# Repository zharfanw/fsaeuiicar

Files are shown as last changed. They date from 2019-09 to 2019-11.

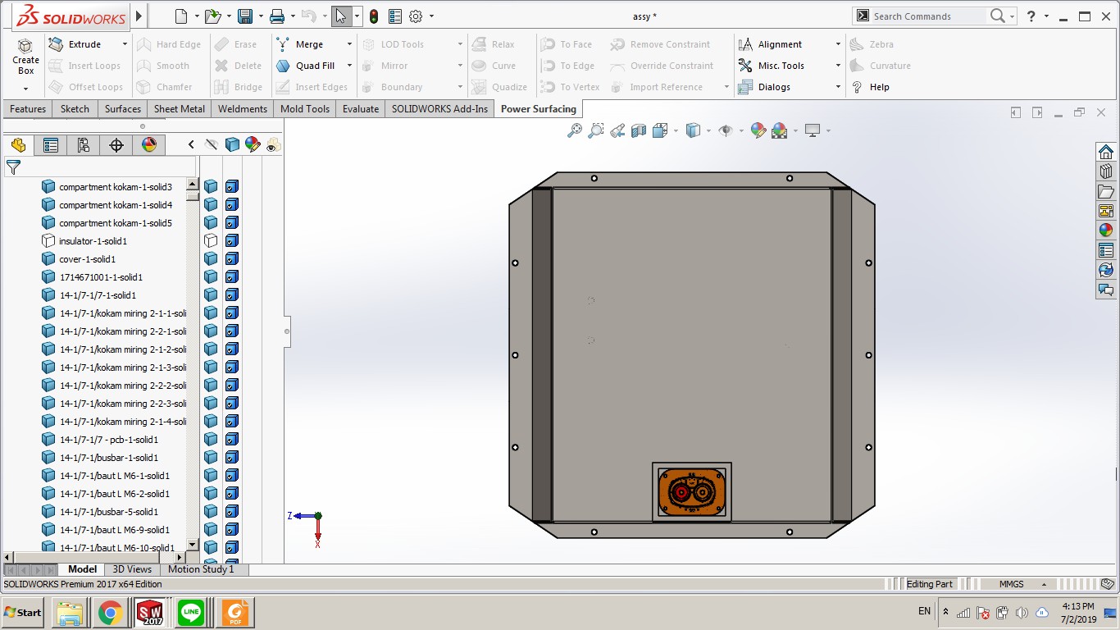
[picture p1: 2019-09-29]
Gambar/messageImage_1562058789128.jpg

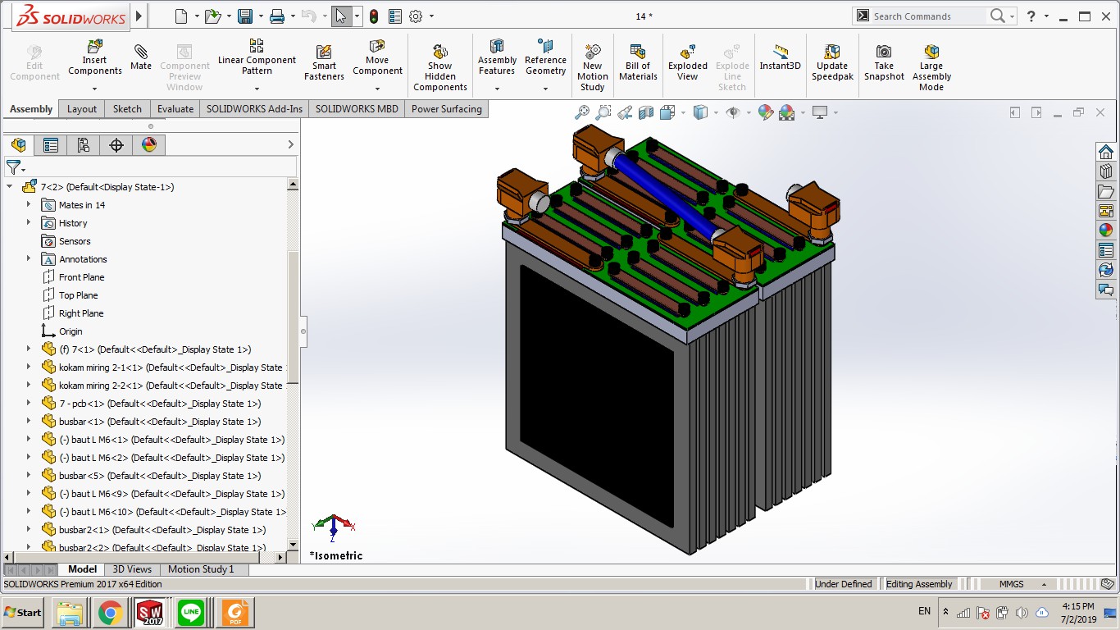
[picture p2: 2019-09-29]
Gambar/messageImage_1562058909561.jpg

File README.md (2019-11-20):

# UIIs Formula Students Car 2018
Repo ini merupakan dokumentasi dari mobil listrik UII 2018.
## Dokumentasi Link
Full PDF Dokumentasi [klik dsini](https://github.com/zharfanw/fsaeuiicar/blob/master/Dokumentasi/Dokumentasi%20Elektrik%20Mobil%20SFJ2018%20UII_v2.pdf "Dokumentasi Elektrik Mobil SFJ2018 UII_v2.pdf")
## Kontributor Dokumentasi

 - Muhammad Zharfan Wiranata
 - Muh Fanriado
 - Kristamayu
 - Rudi Arta
 - Akhid Sulthoni
 - Fauzi HPM
 - Muh Dzulfiqar
 - Refhan Naparin
 - Hilal Pambudi
 - Faiz Isbat
 - Muh Iqbal
 - Jabar Lazuarde

<!--stackedit_data:
eyJoaXN0b3J5IjpbLTQxOTc5MTk5MiwxOTc0MTc4MTIxLDU1Nz
E1NDAyNl19
-->

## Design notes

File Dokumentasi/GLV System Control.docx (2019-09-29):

 1. Shutdown system

Rule yang terkait dengan Shutdown Circuit

EV 5.7.3:

EV 5.1.2:

EV 5.1.10:

EV 5.1.11:

EV 4.2.4:

EV 4.10.1:

   1.1. Skematik Shutdown System

Skematik diatas merupakan rangkaian shutdown system untuk mengendalikan kontaktor tractive system. Rangkaian menggunakan relay SPDT untuk interlock IMD, AMS dan BSPD. Relay diatas di drive dengan transistor pnp yang dipicu dari IMD, AMD, dan BSPD. Selanjutnya rangkaian tersebut dilengkapi dengan indikator setiap interlock, karena hanya menggunakan sebuah tombol reset. Selain interlock tersebut terdapat 7 switch yang digunakan(HVD, Shutdown right, Shutdown left, Shutdown dashboard, inertia switch, BOTS, dan TSMS) dan setiap switch terhubung Normally Close(NC). Skematik rangkaian diatas digunakan pada mobil FSAE UII gen 1 untuk SFJ 2018 dan telah diuji serta layak digunakan.

Gambar 1: Rangkaian Shutdown System v1.0

Pada rangkaian shutdown system v1.0 semua relay interlock menggunakan Normally Close(NC) sehingga jika ada kerusakan pada rangkaian drive pada relay(contoh: transistor terbakar, saluran IMD/AMS/BSPD putus atau lainnya), rangkaian masih bisa menyalakan tractive system walaupun terjadi kesalahan pada mobil. Tentu hal kejadian tersebut menjadi resiko besar, sehingga dibuat alternatif yang lain untuk shutdown system mobil selanjutnya. Selain itu untuk rangkaian BSPD juga masih perlu diperbaiki yang akan dibahas subbab (1.1.a). Oleh karena itu, rangkaian shutdown system dibuat seperti gambar xx.

Rangkaian shutdown system v2.0 masih dalam bentuk simulasi, namun secara simulasi lebih baik dari pada shutdown system v1.0, karena untuk switch interlock menggunakan kaki Normally Open (NO). Dan juga pada rangkaian menggunakan IC logic CMOS 12 volt, sehingga aliran tidak perlu regulator. Shutdown system v2.0 tidak akan mengaktifkan tractive system jika saluran IMD, AMS, dan BSPD putus atau bahkan rangkaian untuk drive relay(transistor mosfet, IC 40xx series, dll) rusak atau bermasalah. Sama seperti shutdown system v1.0, rangkaian hanya menggunakan sebuah reset dan setiap interlock memiliki indikator.

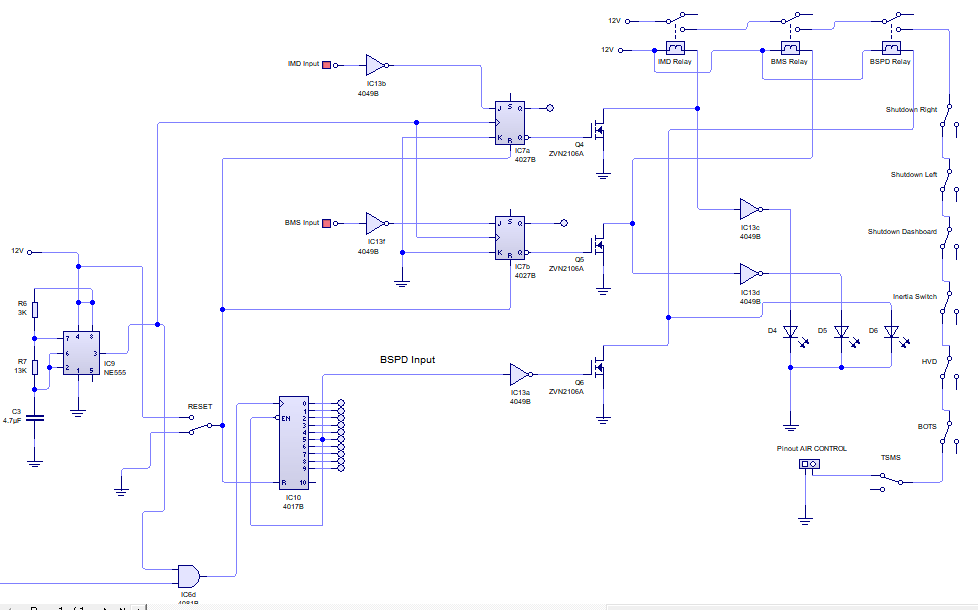
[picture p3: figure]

Gambar 2: Rangakian Shutdown system v2.0

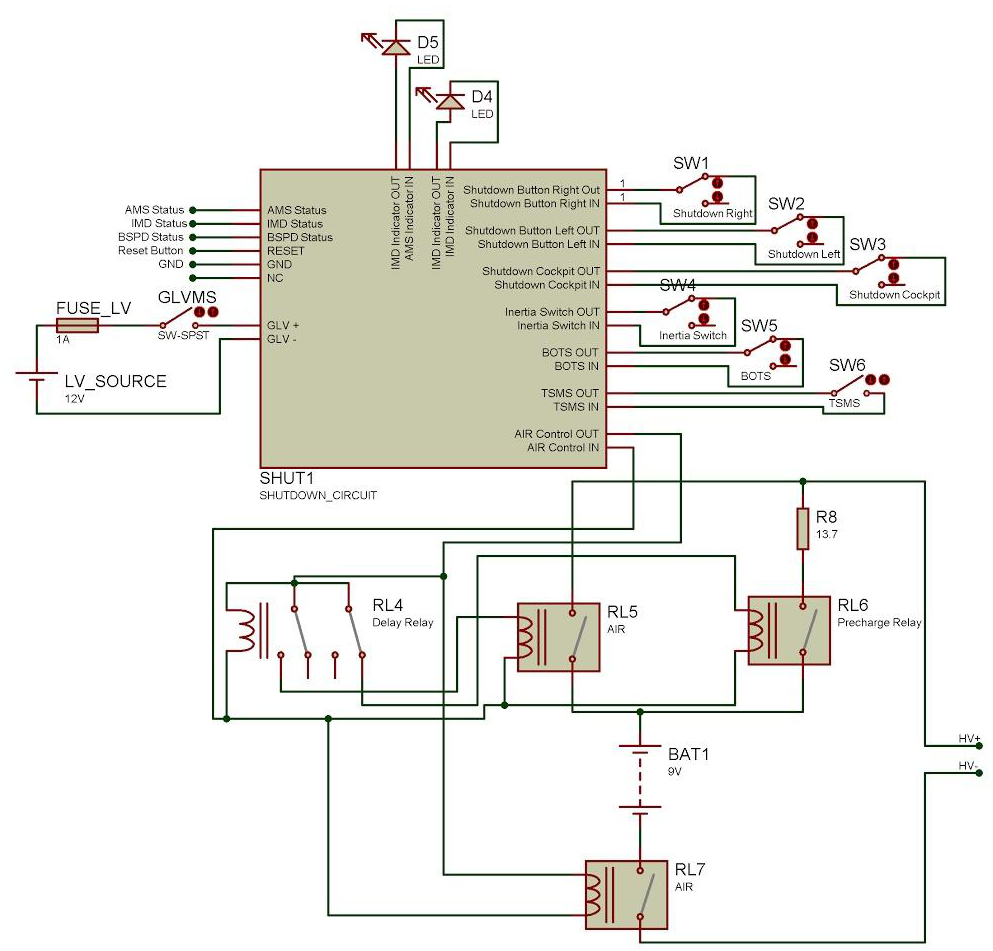
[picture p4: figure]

Gambar 3: AIR Control untuk untuk shutdown circuit

Setelah rangkaian shutdown system , outputnya akan masuk ke rangkaian AIR Control dinama pada rangkaian tang mengendalikan Precharge dan Discharge pada tractive system yang akan dijelaskan pada subbab xx.

     a) Interlock IMD

IMD merupakan perangkat untuk memonitoring resistansi antara chassis/ground dan pole negatif dari tractive system. IMD memiliki 2-3 Output, namun untuk rangkaian shutdown system, hanya menggunakan sebuah output yakni OKHS pada pin 7, karena IMD yang digunakan pada EV FSAE UII sesuai dengan datasheet yang telah diberikan. Untuk lebih jelas tentang spesifikasi IMD yang digunakan, terdapat pada tabel dibawah ini

Make / Model | Bender IR155
Supply voltage | 12 VDC
Environmental temperature range: | -40 … +105°C
Self-test interval: | after power on and every 5 minute
High voltage range: | DC 0..800V
Set response value: | 200kΩ (500Ω/Volt)
Max. operation current: | 150mA
Approximate time to shut down at 50% of the response value: | 5s
Datasheet | Datasheet

Berdasarkan datasheet IMD memiliki rangkaian internal pada pinout IMD seperti illustrasi dibawah ini, (OKHS mengikuti rangkaian M-)

Oleh karena itu keluarannya di pulldown dengan resistor 2.2K ohm. Kemudian jika resistansi antara chassis/ground dan pole negative tractive system dibawah standard resistansi IMD, maka output tersebut akan berlogika 0, begitu pula sebaliknya. Sehingga untuk pada interlock IMD untuk shutdown system v1.0 menggunakan rangkaian seperti dibawah ini,

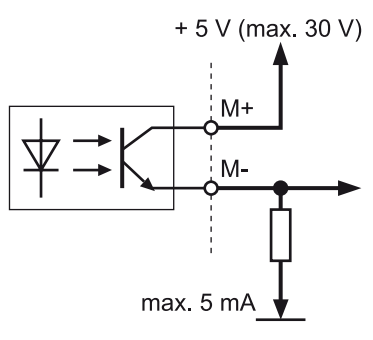
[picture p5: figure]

Gambar 4: Rangkaian Internal output OKHS

Gambar 5: Interlock IMD pada shutdown system v1.0

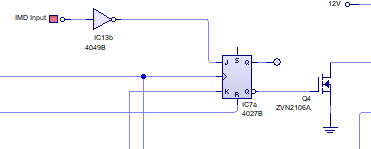
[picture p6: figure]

Gambar 6: Interlock IMD pada shutdown system v2.0

Tentang batasan standar resitansi antara chassis/ground dan HV untuk mobil EV FSAE UII adalah 80k Ohm, resistansi ini berdasarkan rule EV5.5 dimana untuk mobil tersebut memliki 320 Volt, sehingga mobil harus IMD dengan nilai responsenya adalah 500ohm/volt yang artinya untuk mobil bernilai 160k ohm, selanjutnya untuk pengujian IMD pada mobil menggunakan setengah dari nilai response tersebut. Untuk pengujian IMD tersebut, langkah kerja IMD adalah sebagai berikut:

1. sistem LV menyala terlebih dahulu, kemudian IMD menyala dan terhubung dengan HV serta tidak tedeteksi kesalahan pada IMD.
2. Kemudian pada Technical Inspection, maka digunakan resistor 80k ohm untuk menghubungkan antara GLV dan -HV
3. Setelah terdeteksi kesalahan, output OKHS akan active low atau berlogika nol
4. Kemudian dengan rangkaian shutdown system diatas, maka akan terjadi interlock dan menahan kondisi sampai tombol reset ditekan.
     b) Interlock BMS

BMS yang digunakan untuk mobil merupakan ORION BMS, sehingga output BMS yang digunakan shutdown system adalah pin multi purpose output pada pin ke 23. Rangkaian output secara internal di ilustrasikan pada gambar xx

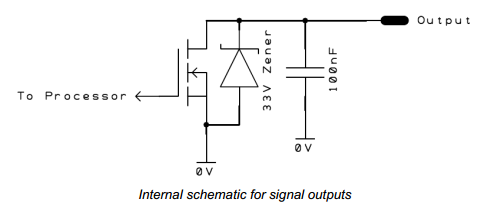
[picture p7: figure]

Gambar 7: Rangkaian internal output ORION BMS

Dengan rangkaian tersebut, maka untuk memanfaatkan output tersebut untuk memicu interlock pada shutdown system maka digunakan rangkaian seperti dibawah ini

Gambar 8: Rangkaian interlock pada BMS pada shutdown system v1.0

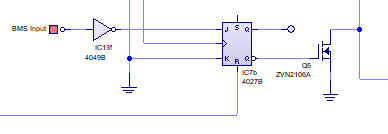
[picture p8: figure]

Gambar 9: Rangkaian Interlock BMS pada shutdown system v2.0

Sinyal multi purpose output pada ORION BMS sejatinya bisa diatur pada aplikasi desktop yang disediakan oleh ORION BMS, namun pada rangkaian interlock diatas telah diatur bahwa output keluaran ORION BMS tersebut ketika terjadi kesalahan adalah active low.

Output

     c) Interlock BSPD

Aturan BSPD

Cara membuat rekayasa interlock

   1.2. Switch untuk Shutdown Circuit
   1.3. Location Switch

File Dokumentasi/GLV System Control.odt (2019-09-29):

Sistem Kontrol pada Low Voltage system Mobil FSAE UII gen 1

Ditulis oleh:

Muhammad Zharfan Wiranata (14524109)

UASC Research Team

Fakultas Teknologi Industri

Universitas Islam Indonesia

2018

1. Sistem Low voltage Mobil FSAE UII gen 1

fasd

2. Shutdown system

Rule yang terkait dengan Shutdown Circuit

EV 5.7.3:

EV 5.1.2:

EV 5.1.10:

EV 5.1.11:

EV 4.2.4:

EV 4.10.1:

  1. Skematik Shutdown System

Skematik pada gambar 1 merupakan rangkaian shutdown system untuk mengendalikan kontaktor tractive system. Rangkaian menggunakan relay SPDT untuk interlock IMD, AMS dan BSPD. Relay diatas di drive dengan transistor pnp yang dipicu dari IMD, AMD, dan BSPD. Selanjutnya rangkaian tersebut dilengkapi dengan indikator setiap interlock, karena hanya menggunakan sebuah tombol reset. Selain interlock tersebut terdapat 7 switch yang digunakan(HVD, Shutdown right, Shutdown left, Shutdown dashboard, inertia switch, BOTS, dan TSMS) dan setiap switch terhubung Normally Close(NC). Skematik rangkaian diatas digunakan pada mobil FSAE UII gen 1 untuk SFJ 2018 dan telah diuji serta layak digunakan.

Gambar 1: Rangkaian Shutdown System v1.0

Pada rangkaian shutdown system v1.0 semua relay interlock menggunakan Normally Close(NC) sehingga jika ada kerusakan pada rangkaian drive pada relay(contoh: transistor terbakar, saluran IMD/AMS/BSPD putus atau lainnya), rangkaian masih bisa menyalakan tractive system walaupun terjadi kesalahan pada mobil. Tentu hal kejadian tersebut menjadi resiko besar, sehingga dibuat alternatif yang lain untuk shutdown system mobil selanjutnya. Selain itu untuk rangkaian BSPD juga masih perlu diperbaiki yang akan dibahas subbab (1.1.a). Oleh karena itu, rangkaian shutdown system dibuat seperti gambar 2.

Gambar 2: Rangakian Shutdown system v2.0 Rangkaian shutdown system v2.0 masih dalam bentuk simulasi, namun secara simulasi lebih baik dari pada shutdown system v1.0, karena untuk switch interlock menggunakan kaki Normally Open (NO). Dan juga pada rangkaian menggunakan IC logic CMOS 12 volt, sehingga aliran tidak perlu regulator. Shutdown system v2.0 tidak akan mengaktifkan tractive system jika saluran IMD, AMS, dan BSPD putus atau bahkan rangkaian untuk drive relay(transistor mosfet, IC 40xx series, dll) rusak atau bermasalah. Sama seperti shutdown system v1.0, rangkaian hanya menggunakan sebuah reset dan setiap interlock memiliki indikator.


Gambar 2: Rangkaian Shutdown System v2

Setelah rangkaian shutdown system , outputnya akan masuk ke rangkaian AIR Control dinama pada rangkaian tang mengendalikan Precharge dan Discharge pada tractive system yang akan dijelaskan pada subbab xx.

    a. Interlock IMD

IMD merupakan perangkat untuk memonitoring resistansi antara chassis/ground dan pole negatif dari tractive system. IMD memiliki 2-3 Output, namun untuk rangkaian shutdown system, hanya menggunakan sebuah output yakni OKHS pada pin 7, karena IMD yang digunakan pada EV FSAE UII sesuai dengan datasheet yang telah diberikan. Untuk lebih jelas tentang spesifikasi IMD yang digunakan, terdapat pada tabel dibawah ini

Make / Model | Bender IR155
Supply voltage | 12 VDC
Environmental temperature range: | -40 … +105°C
Self-test interval: | after power on and every 5 minute
High voltage range: | DC 0..800V
Set response value: | 200kΩ (500Ω/Volt)
Max. operation current: | 150mA
Approximate time to shut down at 50% of the response value: | 5s
Datasheet | Datasheet

Berdasarkan datasheet IMD memiliki rangkaian internal pada pinout IMD seperti illustrasi dibawah ini, (OKHS mengikuti rangkaian M-)

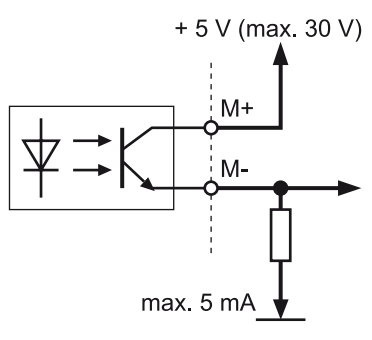
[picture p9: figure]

Gambar 3: Rangkaian internal output IMD

Oleh karena itu keluarannya di pulldown dengan resistor 2.2K ohm. Kemudian jika resistansi antara chassis/ground dan pole negative tractive system dibawah standard resistansi IMD, maka output tersebut akan berlogika 0, begitu pula sebaliknya. Sehingga untuk pada interlock IMD untuk shutdown system v1.0 menggunakan rangkaian seperti dibawah ini,

Gambar 4: Interlock IMD pada shutdown system v1.0

Tentang batasan standar resitansi antara chassis/ground dan HV untuk mobil EV FSAE UII adalah 80k Ohm, resistansi ini berdasarkan rule EV5.5 dimana untuk mobil tersebut memliki 320 Volt, sehingga mobil harus IMD dengan nilai responsenya adalah 500ohm/volt yang artinya untuk mobil bernilai 160k ohm, selanjutnya untuk pengujian IMD pada mobil menggunakan setengah dari nilai response tersebut. Untuk pengujian IMD tersebut, langkah kerja IMD adalah sebagai berikut:

1. sistem LV menyala terlebih dahulu, kemudian IMD menyala dan terhubung dengan HV serta tidak tedeteksi kesalahan pada IMD.
2. Kemudian pada Technical Inspection, maka digunakan resistor 80k ohm untuk menghubungkan antara GLV dan -HV
3. Setelah terdeteksi kesalahan, output OKHS akan active low atau berlogika nol
4. Kemudian dengan rangkaian shutdown system diatas, maka akan terjadi interlock dan menahan kondisi sampai tombol reset ditekan. (Tombol reset tidak boleh mudah diakses oleh driver)
    a. Interlock BMS

BMS yang digunakan untuk mobil merupakan ORION BMS, sehingga output BMS yang digunakan shutdown system adalah pin multi purpose output pada pin ke 23. Rangkaian output secara internal di ilustrasikan pada gambar xx


Gambar 5: Rangkaian internal output ORION BMS

Dengan rangkaian tersebut, maka untuk memanfaatkan output tersebut untuk memicu interlock pada shutdown system maka digunakan rangkaian seperti dibawah ini

Gambar 6: Rangkaian interlock pada BMS pada shutdown system v1.0


Gambar 7: Rangkaian Interlock BMS pada shutdown system v2.0

Sinyal multi purpose output pada ORION BMS sejatinya bisa diatur pada aplikasi desktop yang disediakan oleh ORION BMS, namun pada rangkaian interlock diatas telah diatur bahwa output keluaran ORION BMS tersebut ketika terjadi kesalahan adalah active low.

Output

    a. Interlock BSPD

Berdasarkan rule EV5.6 Brake System Plausibility Device (BSPD)

"A standalone non-programmable circuit must be used on the car such that when braking hard (without locking the wheels) and when a positive current is delivered from the motor controller (a current to propel the vehicle forward), the AIRs will be opened. The current limit for triggering the circuit must be set at a level where 5kW of electrical power in the DC circuit is delivered to the motors at the nominal battery voltage. The action of opening the AIRs must occur if the implausibility is persistent for more than 0.5sec. This device must be provided in addition to the plausibility checks which are carried out by the controller which interprets the drivers torque request and delivers torque to the wheels. See also EV5.1.4 and EV5.1.5 regarding the re-activation of the tractive system after triggering of the BSPD."

Berdasarkan aturan tersebut, didapat BSPD dibuat dengan rangkaian elektronik non-programmable(contoh:dibuat tanpa mikrokontroller, mikroprocesser, atau lainnya yang dapat diprogram). BSPD terjadi ketika braking hard dan arus dari arah motor controller ke pole negative battery(letak sensor bisa dilihat di gambar 10) memiliki daya lebih dari 5kW. Kondisi BSPD ini harus mematikan tractive system/membuka hubungan AIR/Shutdown circuit terhubung terbuka dan terjadi interlock jika muncul lebih dari 0.5 seconds. Selanjutnya untuk mengaktifkan kembali tractive system, harus menekan tombol reset seperti mematikan tombol reset pada interlock lainnya.

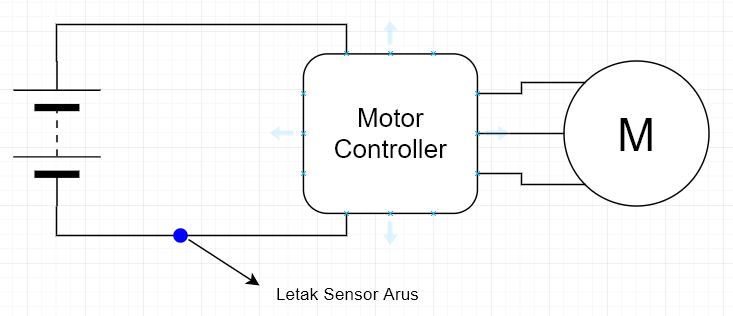
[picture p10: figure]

Gambar 8: Letak posisi sensor arus untuk BSPD

Pada rangkaian BSPD ini, Mobil FSAE UII gen 1 menggunakan sensor arus L06P400S05 produk dari Tamura. Sensor tersebut mampu membaca arus DC dan AC dengan jangkuan effektif dari -400 A sampai +400 A dengan keluaran tegangan dengan jangkuan dari +1V – 4V ilustrasi grafik antara arus yang diukur dengan output tegangan.

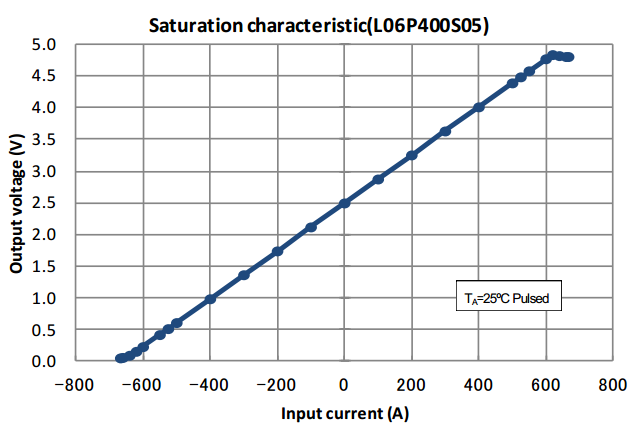
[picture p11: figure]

Gambar 9: Hubungan antara arus dan tegangan keluaran pada sensor L06P400S05

Mobil FSAE UII gen 1, menggunakan battery 320V sebagai tegangan nominal, sehingga untuk mencapai 5 kW maka arus yang lewat adalah 15A. Namun dengan nilai arus tersebut dengan menggunakan sensor L06P400S05 akan memiliki perubahan yang sangat kecil sehingga diperlukan pengkondisi sinyal khusus pembacaan sensor agar mencapai resolusi yang lebih besar. Rangkaian penkondisi sinyalnya adalah sebagai berikut

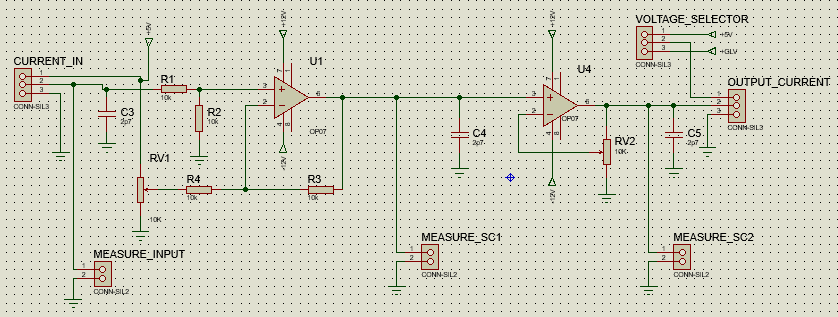
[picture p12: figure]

Gambar 10: Pengkondisi sinyal keluaran sensor arus

Pengkondisi sinyal diawali dengan rangkaian differential untuk menurunkan offset tegangan output pada sensor arus. Offset tersebut dapat diubah sesuai keperluan menggunakan potentio pada RV1, namun pada rancangan mobil FSAE UII gen 1, offset pada pada sensor arus diturunkan sehingga ketika tidak ada arus yang lewat(0 A), maka output tegangan adalah 0 Volt. Dan selanjutnya dikuatkan sesuai keperluan dengan mengatur potensio RV2 setelah itu output akan masuk ke rangkaian BSPD atau rangkaian lainnya untuk dimanipulasi.

Selanjutnya pada rangkaian BSPD, sesuai dengan aturan EV5.6, maka rangkaian v1 pada BSPD seperti dibawah ini

Rangkaian BSPD v1 diatas terdapat komparator arus dan komparator Brake yang kemudian masuk pada gerbang AND untuk output berupa status BSPD sementara. Selanjutnya output tersebut terhubung dengan low-pass filter yang dilengkapi dengan komparator untuk menunda selama 0.5s yang bisa diatur pada potentio RV3 pada rangkaian. Dan output pada keluaran komparator menjadi output BSPD yang akan digunakan pada rangkaian shutdown system v1.

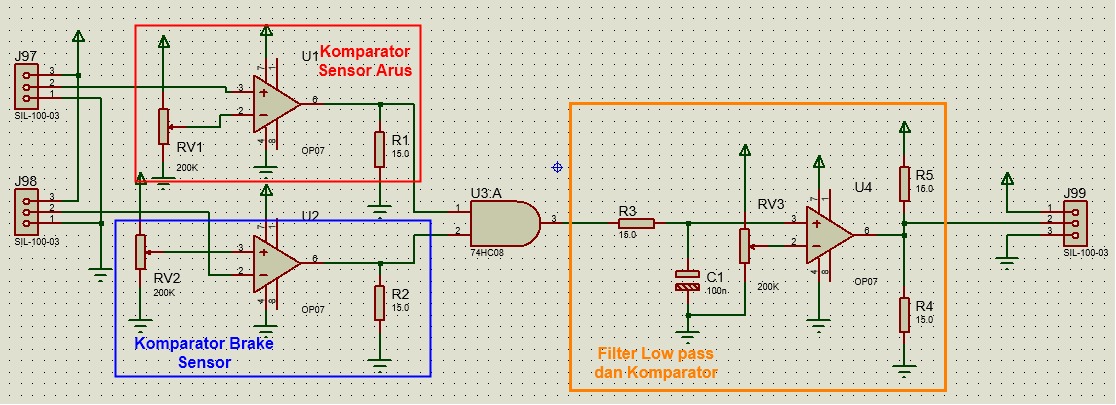
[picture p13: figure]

Gambar 11: Rangkaian BSPD v1 beserta penjelasan fungsinya

Namun rangkaian BSPD v1 masil memiliki kelemahan yang tidak dinginkan pada filter dan komparator untuk menunda selama 0.5s. Hal ini dikarenakan waktu menunda tergantung pada proses charge/discharge pada kapasitor filter. Sehingga output pada BSPD tersebut tidak menunda tepat 0.5s. Oleh Karena itu perlu perbaikan untuk waktu penundaanya, maka untuk perbaikan tersebut maka didapat desain seperti dibawah ini

Pengganti rangkaian BSPD ini menggunakan gerbang logika CMOS 40xx series sehingga dapat menggunakan logika dengan level 12 volt. Dan untuk penundaan waktunya menggunakan shutdown clock dengan frekuensi 10Hz yang akan memberinyal counter. Selanjutnya output pada BSPD terdapat pada kaki Q5 pada counter yang akan diteruskan ke rangkaian shutdown circuit v2.

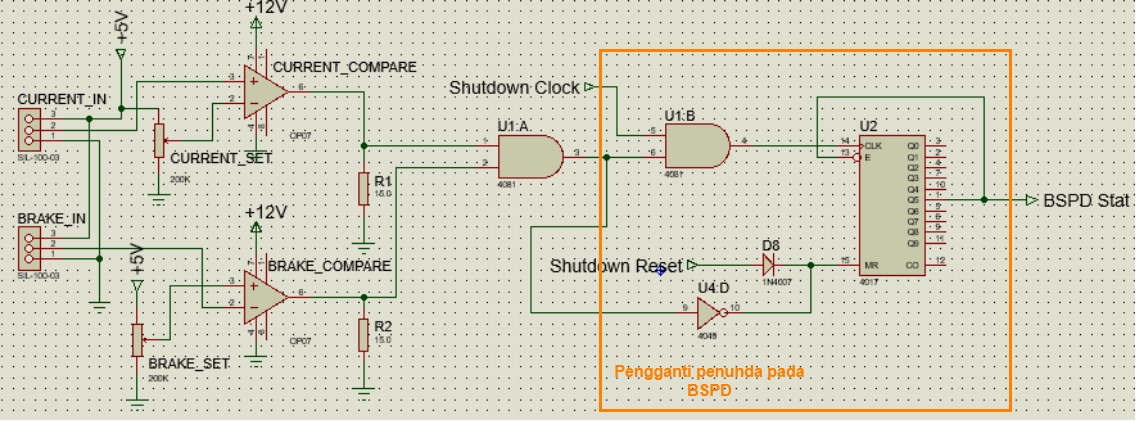
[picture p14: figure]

Gambar 12: Rangkaian BSPD v2 dengan penjelasan fungsinya

    a. AIR Control

Keluaran pada output rangkaian shutdown system akan digunakan pada rangkaian AIR Control. Rangkaian tersebut berfungsi untuk mengendalikan AIR agar dapat melakukan proses Precharge dan Discharge pada rangkaian tractive system. Rangkaiannya seperti dibawah ini

Pada rangkaian ini terdapat 4 AIR, 1 delay relay H3Y-2 12 volt, resistor 1k dan 2k dengan daya 30watt, dan relay SPDT 12volt. Untuk semua AIR, rangkaian tersebut menggunakan kontaktor dari TE Connectivity KILOVAC EV200 dengan seri EV200AAANA. Pada rangkaian diatas, benar tidak boleh menggunakan fuse untuk rangkaian precharge dan discharge(perhatikan EV4.11.6). Rangkaian diatas telah dilengkapi dengan rangkaian precharge dan discharge yang akan dijelaskan dibawah ini.

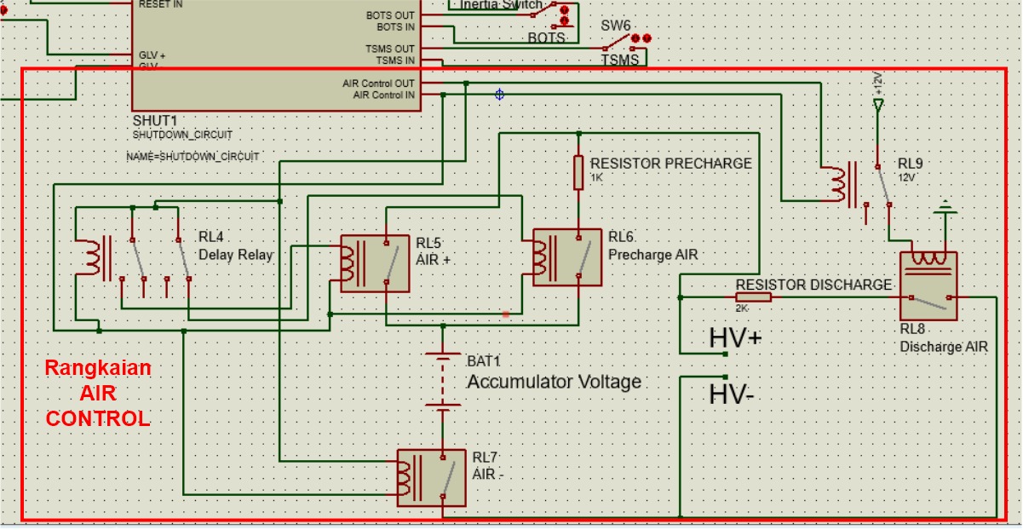
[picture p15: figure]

Gambar 13: Rangkaian AIR Control pada keluaran shutdown system

Rangkaian Precharge

Berdasarkan EV 4.11.1 rangkaian tractice system harus melakukan precharge sampai tegangan tractive mencapai 90% dari tegangan penuhnya. Hal ini dilakukan untuk melakukan charging pada kapasitor yang terhubung dengan tractive circuit. Kapasitor pada mobil FSAE UII gen 1 yang terhubung dengan tractive system jika diakumulasi memiliki nilai sebesar 1mF. Dengan menggunakan persamaan charging kapasitor dibawah ini

V_TScapacitor = V_Source times ( 1-e^( {-t} over {rc} ) ) .....(1)

*Program Precharge MATLAB terlampir

Dan jika kita menggunakan resistor 1k sebagai resistor precharge maka hasil rangkaian precharge tersebut menghasilkan grafik dibawah ini,

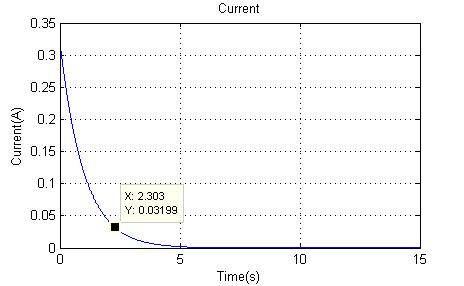
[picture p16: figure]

Gambar 14: Arus yang melewati resistor precharge

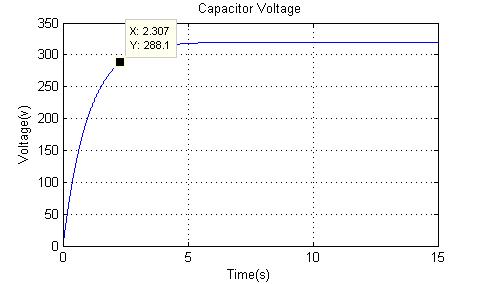
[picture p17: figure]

Gambar 15: Tegangan pada tractice system selama precharge

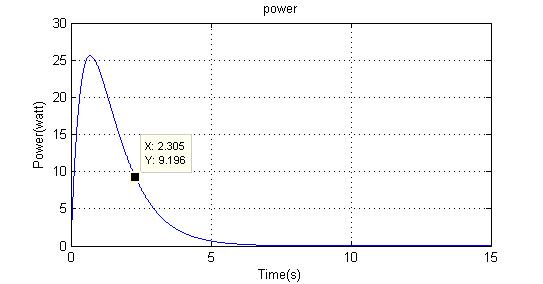
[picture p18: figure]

Gambar 16: Daya yang terdapat pada resistor precharge

Dengan berdasarkan data diatas, daya maksimal yang lewat pada resistor tidak mencapai 30 watt dan untuk mencapai 90% tegangan maksimum diperlukan waktu 3 detik atau kurang. Oleh karena itu, pada delay relay kita atur penundaannya mencapai 3 detik.

Rangkaian Discharge

Rangkian discharge dirancang sesuai dengan aturan EV4.11.4 dan EV5.1.3 bahwa proses discharge harus dibawah 5 detik dan tegangan kurang dari 60 VDC. Maka dari itu dengan menggunaka persamaan discharge kapasitor dibawah ini

V_TSDischarge = V_source times e^( -t over rc) .... (2)

*Program Discharge MATLAB terlampir

Dan kapasitor 1mF pada tractive system dan resistor discharge 2k maka proses discharge adalah sebagai berikut,

Dengan menggunakan pemilihan resistor tersebut, proses discharge mencapai dibawah 60 volt tidak membutuhkan waktu 5 detik.

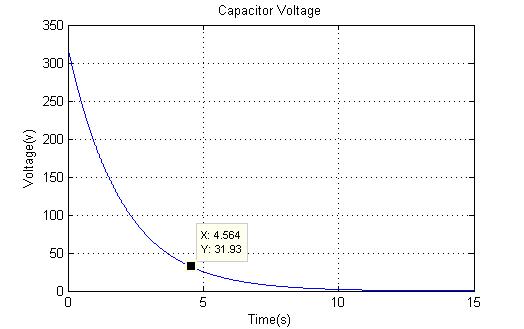
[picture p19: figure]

Gambar 17: Tegangan TS pada proses discharge

*Note : Proses perancangan rangkaian precharge dan discharge harus benar-benar memperhatikan spesifikasi resistor, kontaktor, relay, delay relay, dan lainnya. Spesifikasi bisa dilihat di datasheet masing-masing perangkat. Kesalahan perancangan akan berakibat fatal

  1. Switch untuk Shutdown Circuit dan lokasinya
    a. Shutdown Button
    b. BOTS
    c. Inertia Switch
    d. HVD Interlock
    e. TSMS
3. TSAL (Tractive System Active Light)

TSAL (Tractive System Acive Light) merupakan indikator tractive system pada mobil. Indikator ini mengikuti EV4.12 sebagai berikut:

EV4.12.2 The TSAL itself must:

a. Be directly controlled by the voltage present within the tractive system using hard wired electronics. Software control is not permitted.
b. Be red in color.
c. Flash continuously with a frequency between 2Hz and 5Hz when illuminated.

EV4.12.3 The TSAL mounting location must:

a. Be near the main roll hoop at the highest point of the vehicle.
b. Be mounted lower than the highest point of the main roll hoop.
c. Be no lower than 150 mm from the highest point of the roll hoop.
d. Not allow contact with the driver’s helmet in any circumstances.
e. Not be in proximity to other lights.

EV4.12.4 The TSAL must be visible:

a. From every horizontal direction, except small angles which are blocked by the main roll hoop.
b. From a point 1.6m vertically from ground level, within a 3m horizontal radius from the TSAL.
c. In direct sunlight.

Dengan berdasarkan aturan diatas, maka desain TSAL untuk Mobil FSAE UII gen 1 dijelaskan dibawah ini,

  1. Skematik dan Layout TSAL

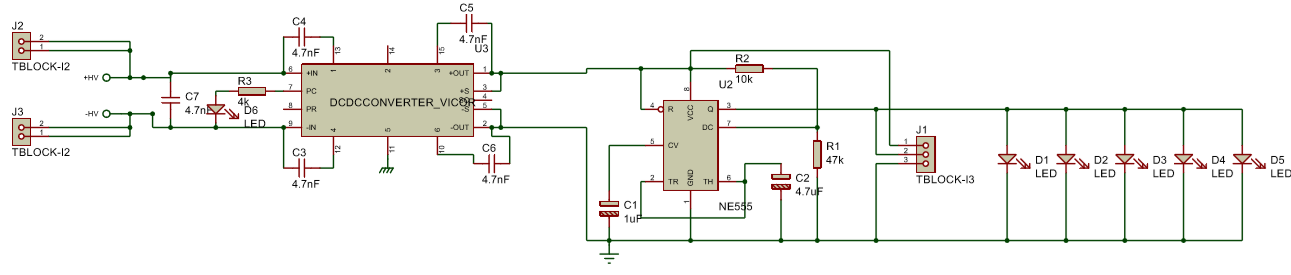
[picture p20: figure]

Gambar 18: Skematik rangkaian TSAL

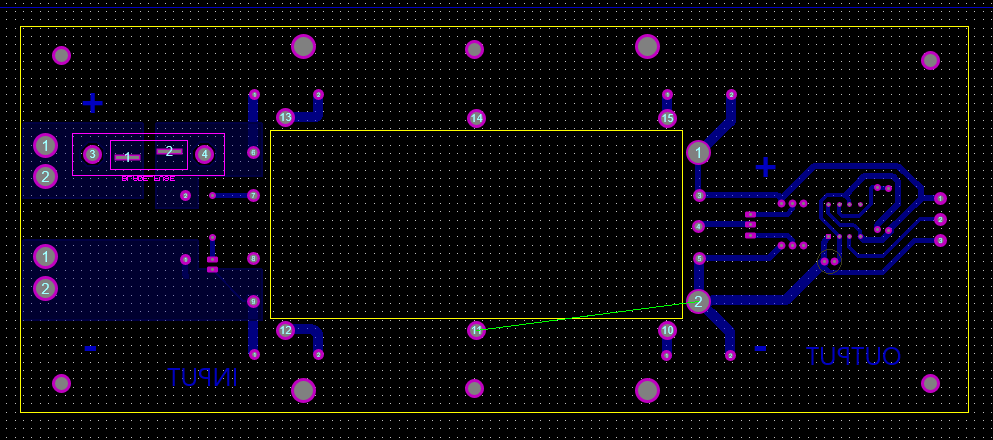
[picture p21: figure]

Gambar 19: Layout TSAL

Make/Model: | High Power LED
Color: | RED indicated Tractive System ON
Flash Rate: | 3Hz
Powered By: | Tractive system
Controlled By: | Tractive System have Isolated DC-DC converter that can used as supply for TSAL. We used that DC-DC output that triggered by HV because the DC-DC are directly connected through the Tractive. The DC-DC Converter only on when HV get input from 180V to 375V
TS Turn On Voltage: | Belum pernah ditest
TS Turn Off Voltage: | Belum pernah ditest

TSAL menggunakan sebuah Isolated DC-DC Converter dari Vicor dengan seri V300A15C500BL. Selanjutnya dengan menggunakan rangkaian pendetak untuk membuat indikator tractive system. Namun rangkaian ini belum ditest perihal keaktifan DCDC Converter tersebut.

Lampu indikator yang digunakan merupakan lampu strip LED merah dengan tegangan 12 volt.

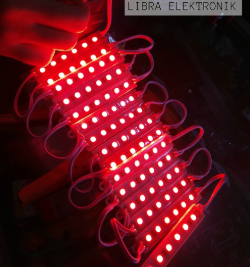
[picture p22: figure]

  1. Lokasi TSAL
4. BMS (Battery Management System)
  1. Spesifikasi BMS
  2. Sensor Temperature
  3. Pengukuran tegangan BMS
  4. Lokasi BMS
5. Charging
  1. Spesifikasi Charger
  2. Rangkaian tractive system pada proses charging
    a. Charging Shutdown System
    b. Interlock koneksi Charger
    c. Pengendalian Charger
  3. Prosedur charging
6. Power Distribution Module (PDM)
  1. Skematik dan spesidifikasi PDM
  2. DC-DC Converter
7. ECU Brain
  1. Skematik ECU Brain
  2. Spesifikasi ECU Brain
  3. Arsitektur Perangkat Lunak
    a. CAN Bus
  4. Ignition Motor Controller
  5. Data Logging
  6. Telemetri
8. Motor Controller
  1. Spesifikasi
  2. a
9. Pengkabelan umum Mobil FSAE UII gen 1
10. Lampiran
  1. Program Matlab : Precharge
  2. Program Matlab : Discharge
  3. Skematik

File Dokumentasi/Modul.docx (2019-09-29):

Technical Inspection

High Voltage Inspection : Part EV1

11. HV Cables / Connection
12. HV insilation-of-terminal connections
13. GLV Battery
14. Accumulator Container
15. Electrical confirmation of Accumulator Container
16. Energy Meter
17. Rigging of the Accumulator
18. Caution for the HV parts/ Firewall
19. Contact Protection from High Voltage
20. Accumulator Management System
21. Traction Motor Mounting
22. Master Switches

EV5.2.3 : Location of the control system master switch

- The Switch must be located on the right side of the vehicle, at the driver’s shoulder height

Kedua Master Switch harus terletak di sebelah kanan mobil, dengan letaknya sejajar dengan bahu driver

EV5.2.4 : High voltage system master switch

- The switch must be located on the right side of the vehivle, at the driver’s shoulder height

EV5.2.8 : Master switch marking

- Control system: LV - High voltage system: HV

Beri penanda contoh: stiker, untuk menandakan pada setiap master switch

EV5.2.8 : Special marking for the high voltage master switch

- Th switch must have a lightening bolt mark

Khusus untuk master switch HV, menggunakan label/stiker lightening bolt mark

EV5.2.9 : The “ON” position of both master switches must be in the horizontal positions and must be marked accordingly. The “OFF” position of both switches must also be clearly marked

23. a

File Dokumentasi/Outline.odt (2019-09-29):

1. Sistem Mobil FSAE2018
2. Rangkaian Sistem Traktif
  1. Rangkaian sistem traktif
  2. Fusing Diagram
3. Shutdown System
  1. Rangkaian Sistem Shutdown
  2. Wiring
  3. IMD
    1. IMD Spek
    2. Interlok IMD Fault
    3. IMD Indicator
    4. Demonstrasi IMD
  4. BSPD
    1. Sensor Arus BSPD
    2. BSPD Setpoint
    3. Rangkaian BSPD
    4. Lokasi BSPD
    5. Demonstrasi BSPD
  5. Battery Management System
    1. BMS Fault
    2. Interlock BMS Fault
    3. Demonstrasi BMS
4. Sistem Safety
  1. TSAL
    1. Spek TSAL
    2. Rangkaian TSAL
    3. Lokasi TSAL
  2. Titik Pengukuran
    1. Spek Titik Pengukuran
    2. Lokasi Titik Pengukuran
    3. Proteksi titik Pengukuran
    4. Resistor proteksi Titik Pengukuran
    5. Lokasi Resistor proteksi titik pengukuran
    6. Demonstrasi TSMP
  3. HVD
    1. Spek HVD
    2. Lokasi HVD
    3. HVD Koneksi
    4. Demonstrasi HVD
  4. Rangkaian Discharge
    1. Spek Komponen rangkaian Discharge
    2. Lokasi Rangkaian Discharge
    3. Kontrol Rangkaian Discharge
    4. Demonstrasi Discharge
5. Engine Control Unit
  1. Pedal Psaubillity System
  2. Ready to drive
  3. Motor Controller Drive
  4. Antarmuka komunikasi
    1. Protokol
6. Akumulator
  1. Rangkaian Akumulator
  2. Cell
    1. Spek Cell
    2. Konfigurasi elektrik cell
    3. Koneksi cell
    4. koneksi cell
    5. Proteksi overcurrent paralel cell
    6. Cell Mounting
  3. Segments
  4. Rangkaian Precharge
    1. spek Komponen rangkaian precharge
    2. lokasi rangkaian precharge
    3. kontrol rangkaian precharge
  5. BMS
    1. spek BMS
    2. Sensor Temperature
    3. Lokasi sensor Temperature
    4. Sensor tegangan BMS
    5. Overcurrent sensor tegangan BMS
    6. batasan BMS
    7. Lokasi BMS
  6. AIR
    1. Spek AIR
  7. Indikator akumulator
    1. Rangkaian indikator akumulator
  8. Mechanical
    1. Enclosure akumulator
    2. Seperasi AIR dan fuse
  9. Charging
    1. Spek Charging
    2. Sistem Shutdown Charging
    3. rangkaian Charging sistem traktif
    4. Koneksi interlock Charger
    5. Kontrol charger
    6. Demonstrasi charger
7. Motor Controller
8. Power Distribution Module
  1. Rangkaian PDM
  2. Distribusi Daya
  3. Demonstrasi PDM
9. Pengkabelan
10. Firewall
  1. Firewall Layer Specifications
  2. Lokasi Firewall
11. LAMPIRAN
  1. Rangkaian
  2. Rumus
  3. Datasheet
  4. Dokumentasi Gambar Penunjang

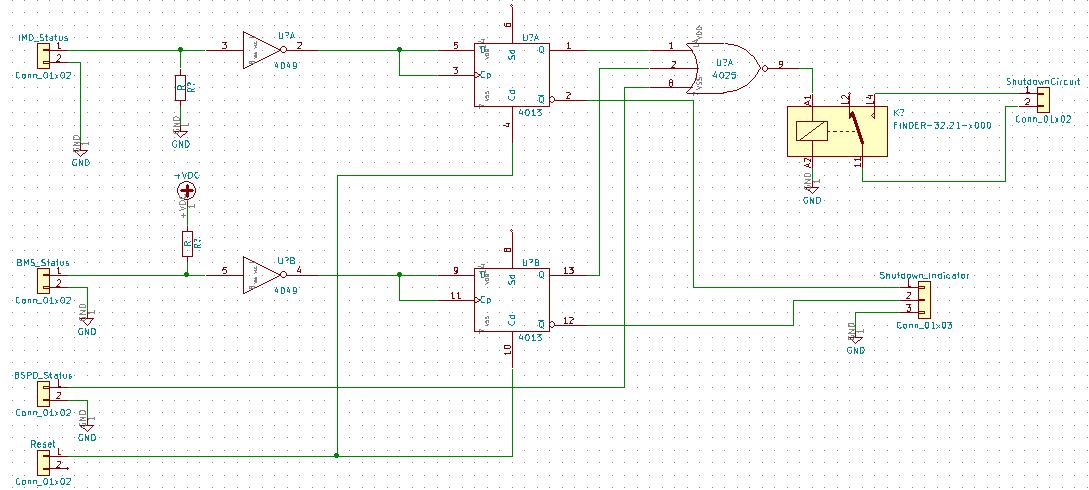
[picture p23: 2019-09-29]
Rangkaian/GambarRangkaian/ShutdownSystemV2.JPG

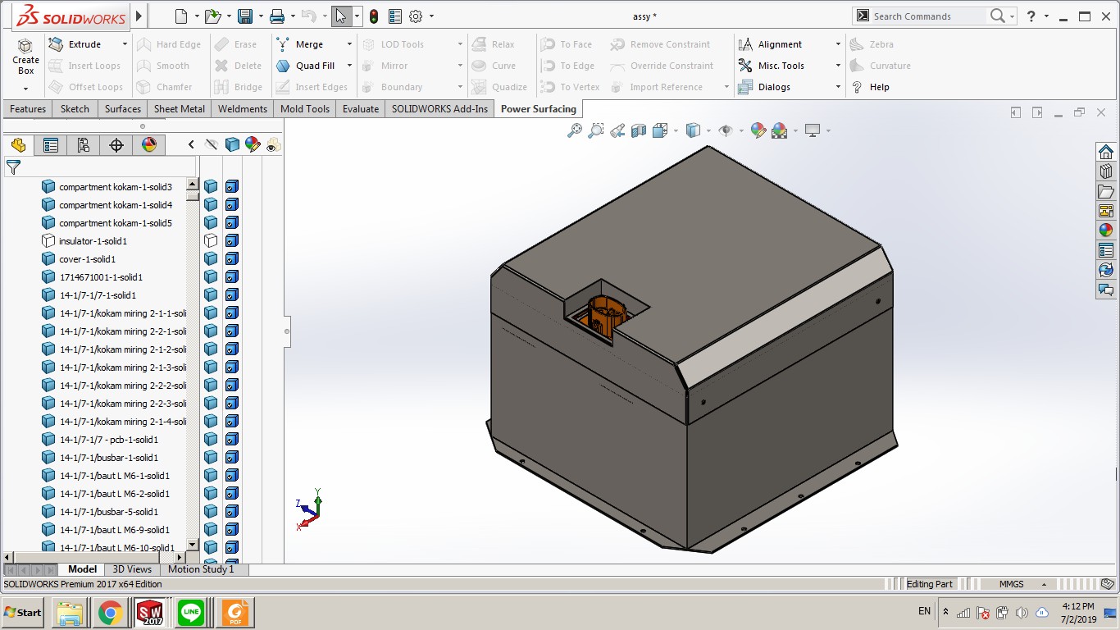
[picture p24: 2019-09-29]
Gambar/messageImage_1562058772510.jpg

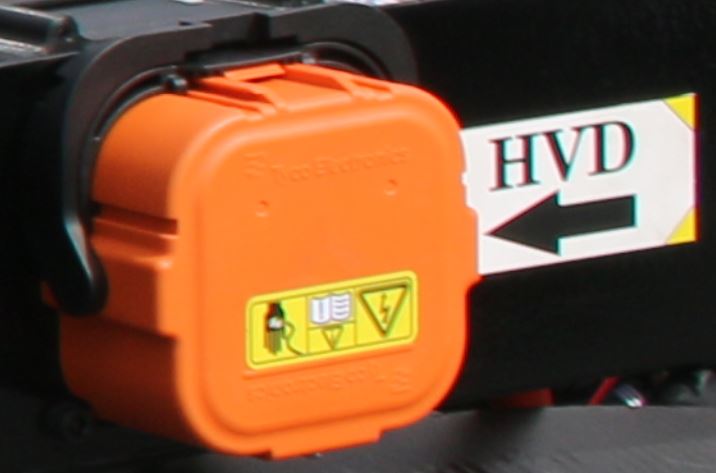
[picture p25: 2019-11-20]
Dokumentasi/FotoHVD.JPG

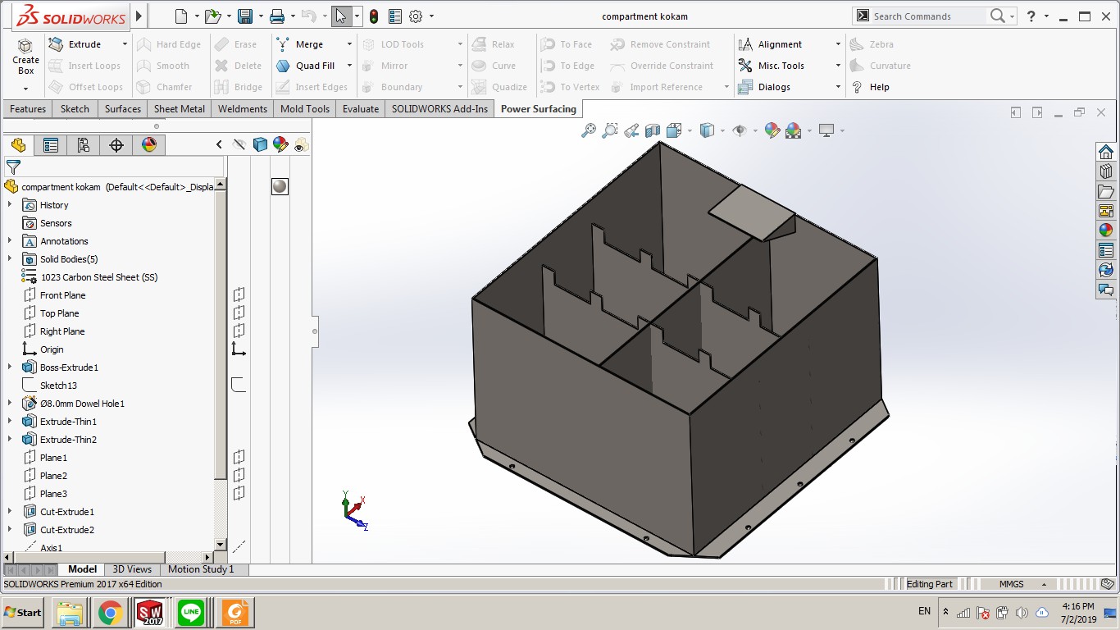
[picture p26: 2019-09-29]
Gambar/messageImage_1562059000362.jpg

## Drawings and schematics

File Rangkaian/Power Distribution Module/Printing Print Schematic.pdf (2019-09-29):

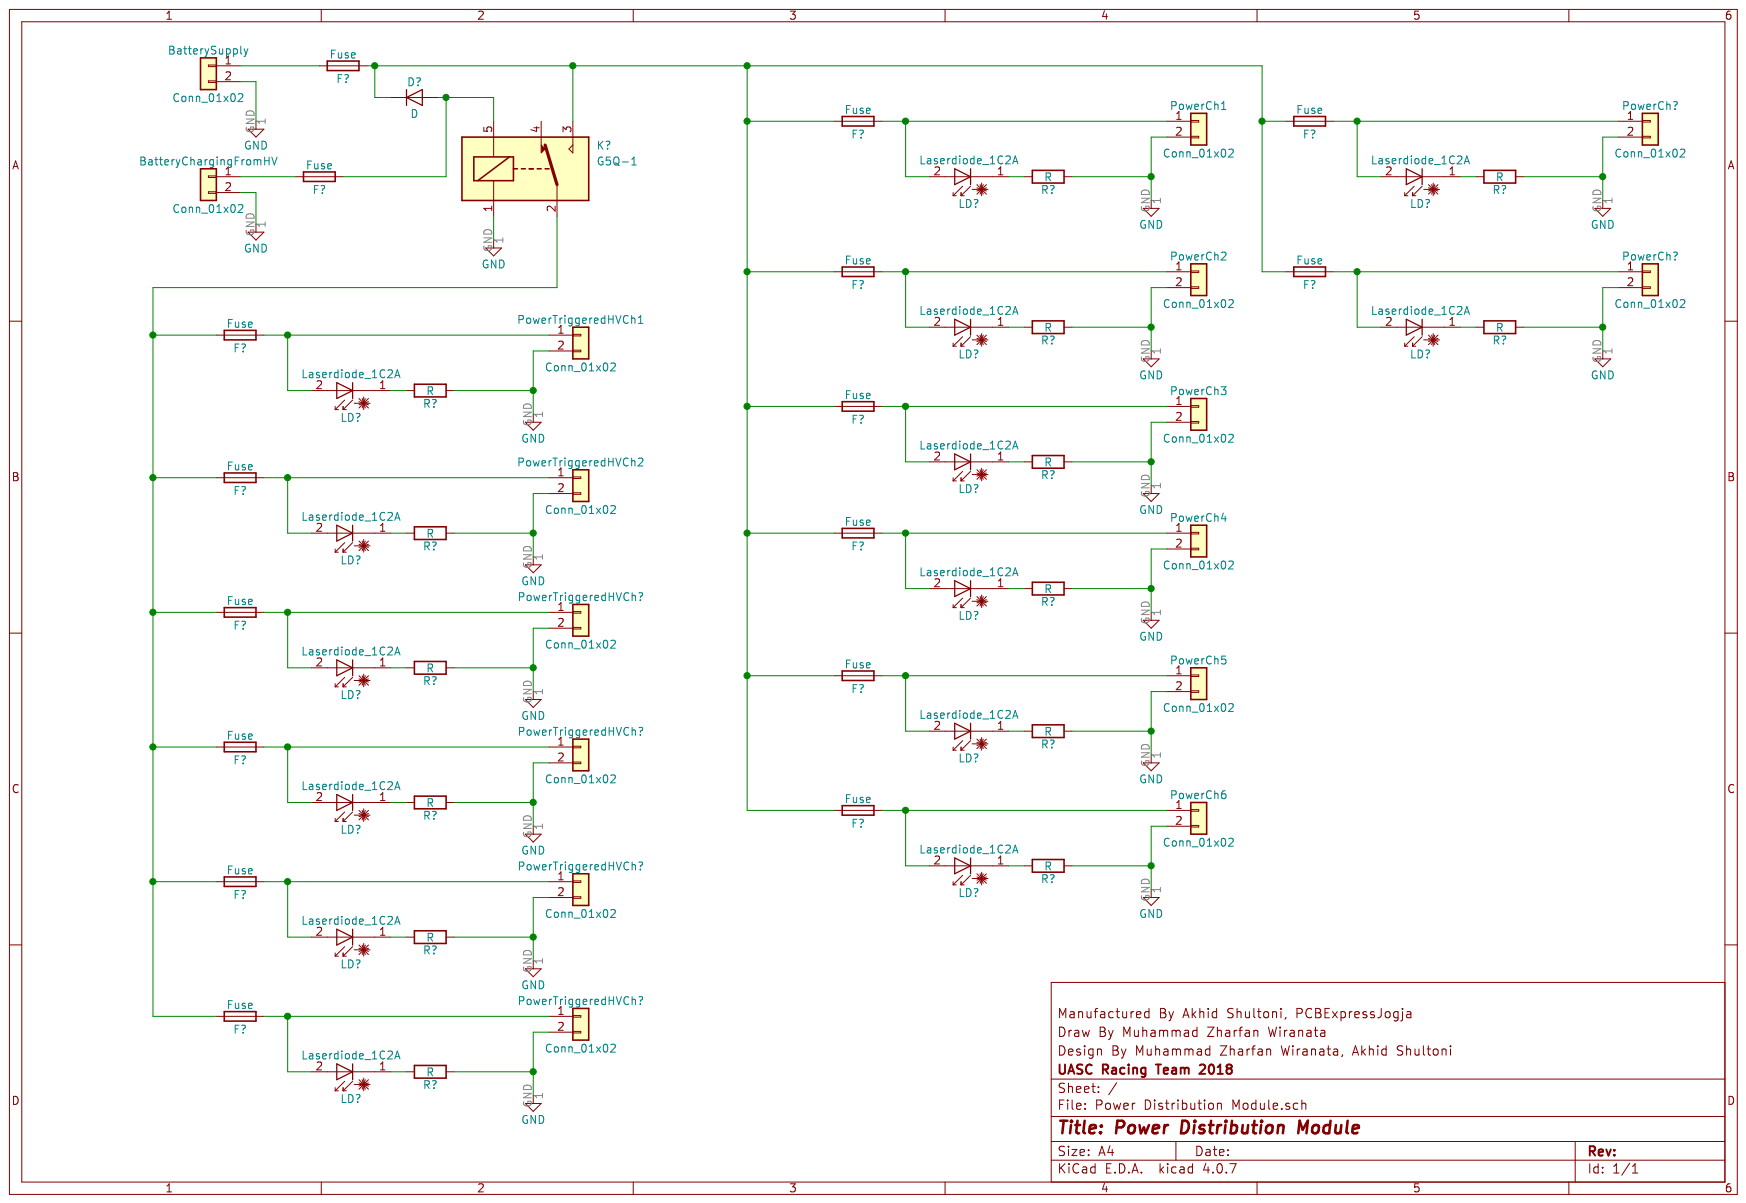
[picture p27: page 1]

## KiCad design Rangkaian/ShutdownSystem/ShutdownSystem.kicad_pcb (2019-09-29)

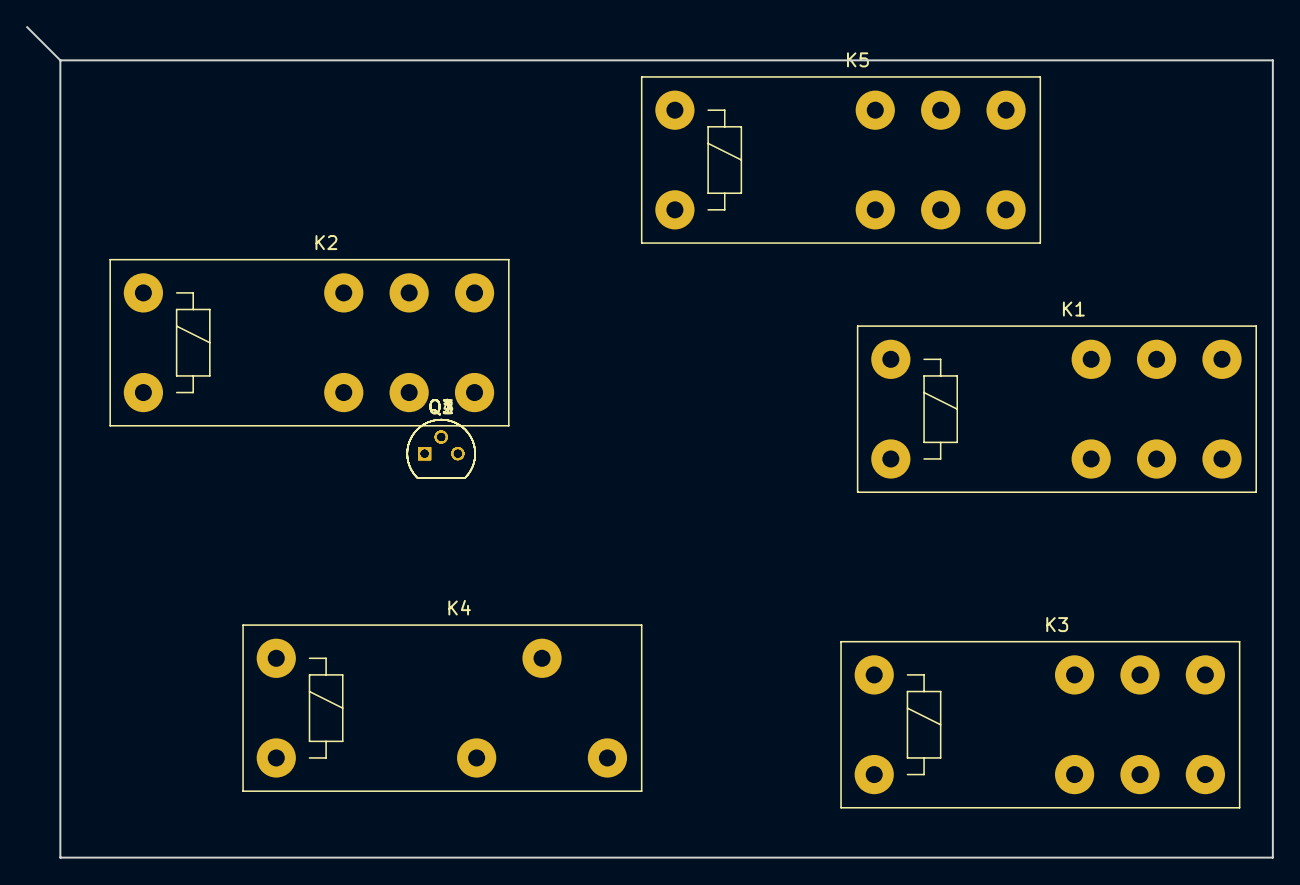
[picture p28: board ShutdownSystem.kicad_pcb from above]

Board: 2 copper layers, 95.3 x 63.5 mm, 9 parts (0 on the bottom side), 10 nets, no tracks yet.

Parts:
K1, K2, K3, K5: FINDER-41.52; Relay_DPDT_Finder_40.52
K4: FINDER-40.51; Relay_SPDT_Finder_40.51
Q1, Q2, Q4: MPSA92; TO-92_Molded_Narrow
Q3: MPSA42; TO-92_Molded_Narrow

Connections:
+VDC: K1.21, K4.11, Q1.1, Q2.1, Q4.1
GND: K1.A2, K2.A2, K3.A2, K4.A1, K5.A1
unnamed: K1.11, K1.A1, Q1.3
unnamed: K2.11, K2.A1, Q2.3
unnamed: K3.11, K3.A1, Q3.1, Q4.3
unnamed: K1.12, K2.12, K3.12
unnamed: K1.22, K2.21
unnamed: K2.22, K3.21
unnamed: K4.A2, K5.11, K5.21, K5.A2
unnamed: Q3.3, Q4.2

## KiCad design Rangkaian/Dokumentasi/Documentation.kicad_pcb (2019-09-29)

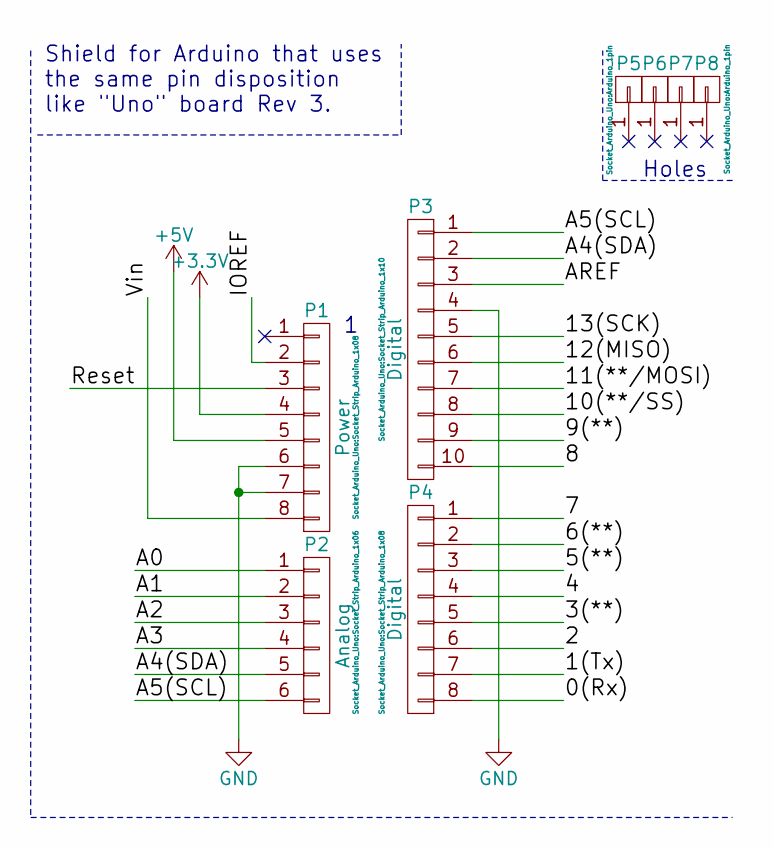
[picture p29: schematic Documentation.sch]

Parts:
P1: Power; Socket_Strip_Arduino_1x08
P2: Analog; Socket_Strip_Arduino_1x06
P3: Digital; Socket_Strip_Arduino_1x10
P4: Digital; Socket_Strip_Arduino_1x08
P5, P6, P7, P8: CONN_01X01; Arduino_1pin

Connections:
+3V3: P1.4
+5V: P1.5
/0(Rx): P4.8
/1(Tx): P4.7
/2: P4.6
/3(**): P4.5
/4: P4.4
/5(**): P4.3
/6(**): P4.2
/7: P4.1
/8: P3.10
/9(**): P3.9
/10(**/SS): P3.8
/11(**/MOSI): P3.7
/12(MISO): P3.6
/13(SCK): P3.5
/A0: P2.1
/A1: P2.2
/A2: P2.3
/A3: P2.4
/A4(SDA): P2.5, P3.2
/A5(SCL): P2.6, P3.1
/AREF: P3.3
/IOREF: P1.2
/Reset: P1.3
/Vin: P1.8
GND: P1.6, P1.7, P3.4

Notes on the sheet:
Holes
Shield for Arduino that uses the same pin disposition like "Uno" board Rev 3.

Board: 2 copper layers, 8 parts (0 on the bottom side), 3 nets, no tracks yet.

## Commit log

2019-09-29 Menambahkan Dokumentasi mobil sementara
    [Accumulator.kicad_pcb, Accumulator.sch, Accumulator_schematic.kicad_pcb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]
2019-11-20 New Update
    [Documentation.kicad_pcb, Documentation.sch, ShutdownSystem.kicad_pcb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]
